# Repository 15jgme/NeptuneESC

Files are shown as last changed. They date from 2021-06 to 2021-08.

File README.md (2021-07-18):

# NeptuneESC
The goal of this project is to create the smallest possible electronic speed controller module for a single motor. This work is essentially Blue Robotic's BlueESC with a different, smaller, board layout. 

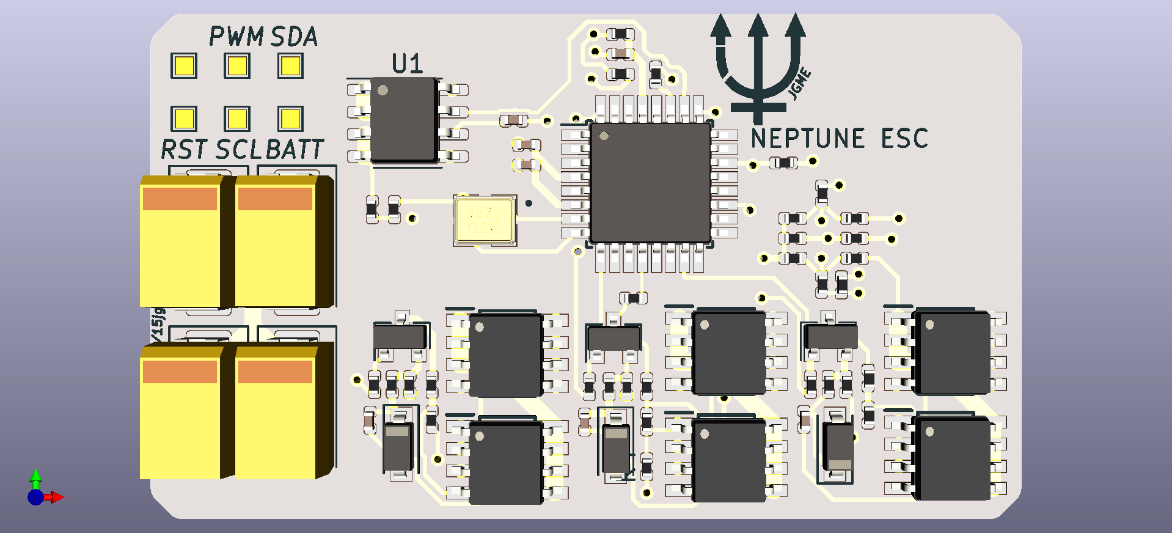
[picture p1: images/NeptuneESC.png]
Board layout


## Quick notes
* Design in KiCad
* ATmega8A-AU MCU
* I2C operations
* 5cm x 3cm size
* Programmable ESC

## Layout

The design is made to be compatable with assembly and board fabrication from [JLCPCB]https://jlcpcb.com/

The current size is about 5cm by 2cm in a single PCB, and is designed to support motors used in midsized UAV applications.

## Usage

As with the BlueESC, Neptune operates on [tgy](https://github.com/bluerobotics/tgy) firmware and can be run off of an I2C connection, making it ideal for daisychaining and tinkering. Note that since this project was in active development tgy is no longer maintained, but the atmega8a-au should allow for a variety of different firmware if desired. 

## State

This project was never assembled, however it is nearly complete. Anyone who needs something similar should have no trouble completing it!
Here's whats left before completion.

* Layout J8 and J7
* Finish about 10 traces and add ground and power planes as desired
* Make better A/B/C channel pads and connectors.
* Electrical checks
* _Fab it!_

If I need a custom ESC I'll continue work on this but until then it's for anyone who can make use of it. Cheers 🍻

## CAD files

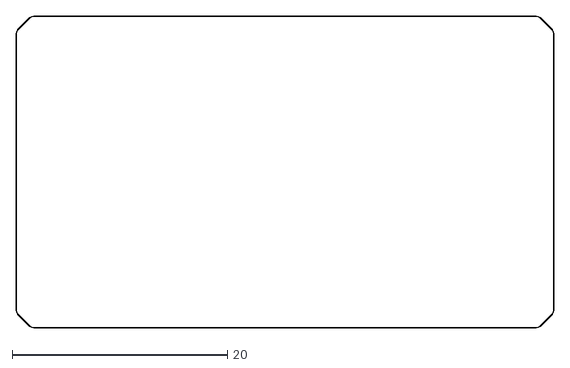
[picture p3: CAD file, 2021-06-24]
Outline/Outline.dxf
50.0 x 29.0

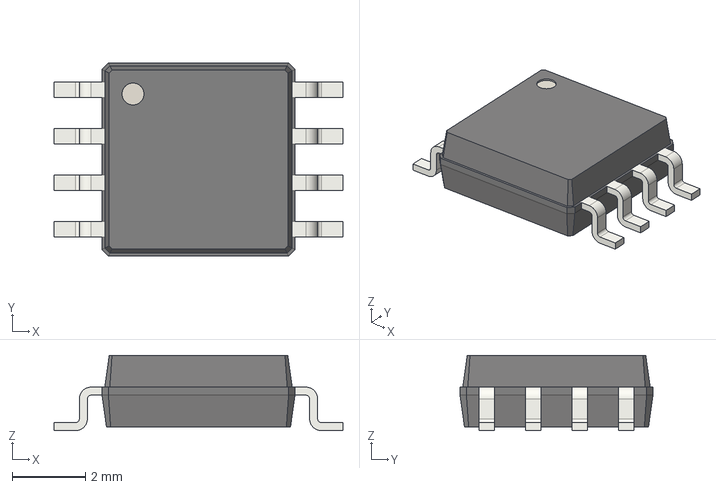
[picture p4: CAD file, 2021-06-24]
Used libraries/SOIC-8_5.275x5.275mm_P1.27mm.step
7.90 x 5.28 x 2.06 mm

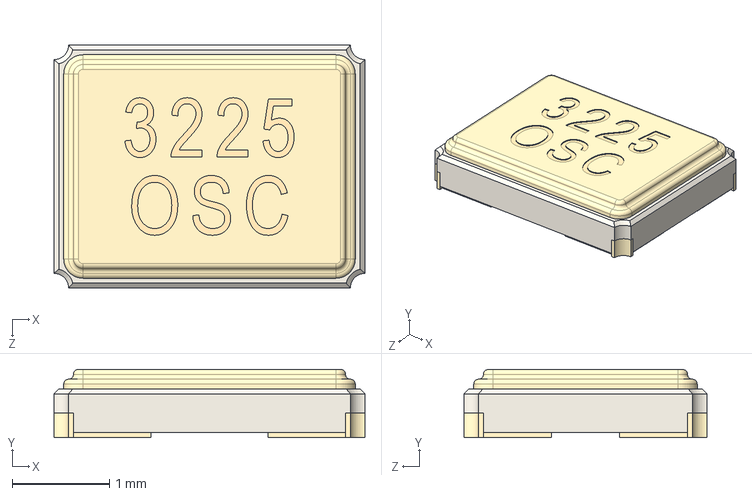
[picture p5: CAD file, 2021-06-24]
Used libraries/3225 SMD Crystal Oscillator.STEP
3.20 x 0.7 x 2.50 mm

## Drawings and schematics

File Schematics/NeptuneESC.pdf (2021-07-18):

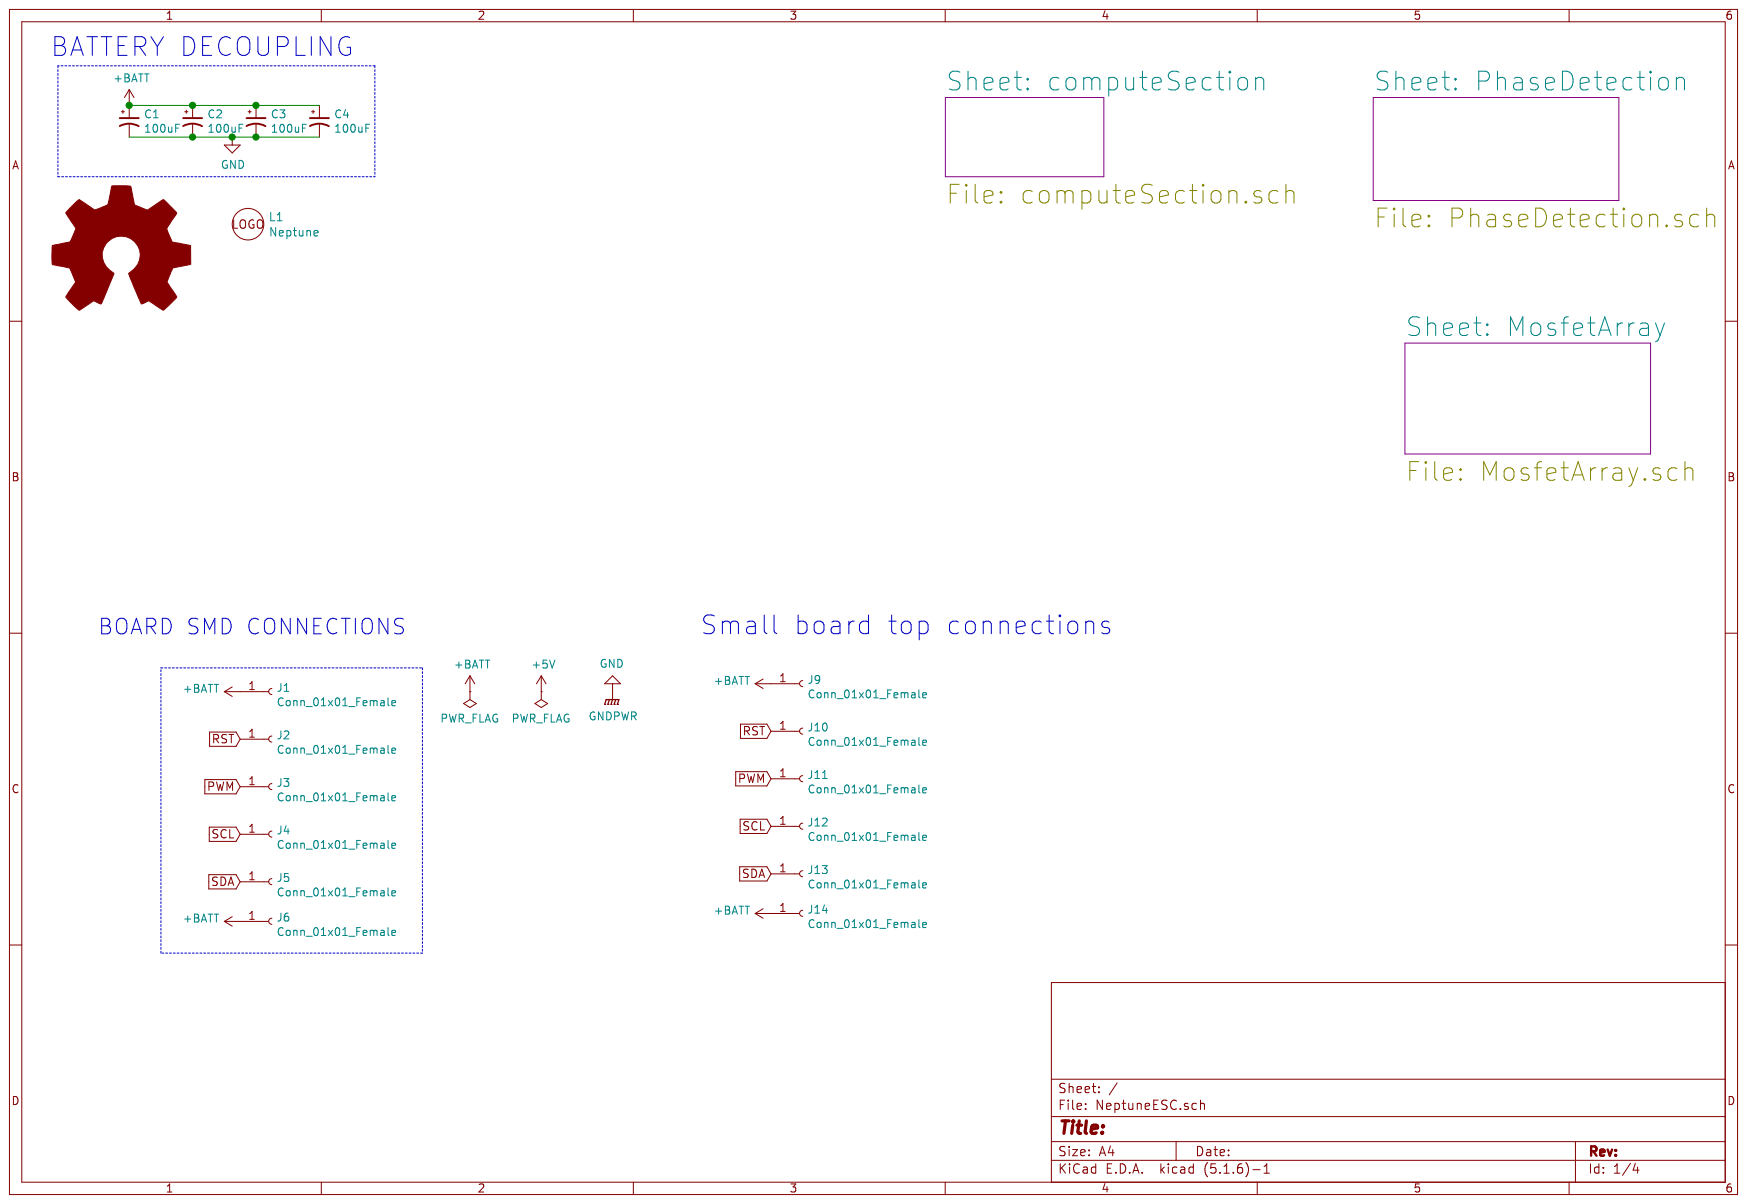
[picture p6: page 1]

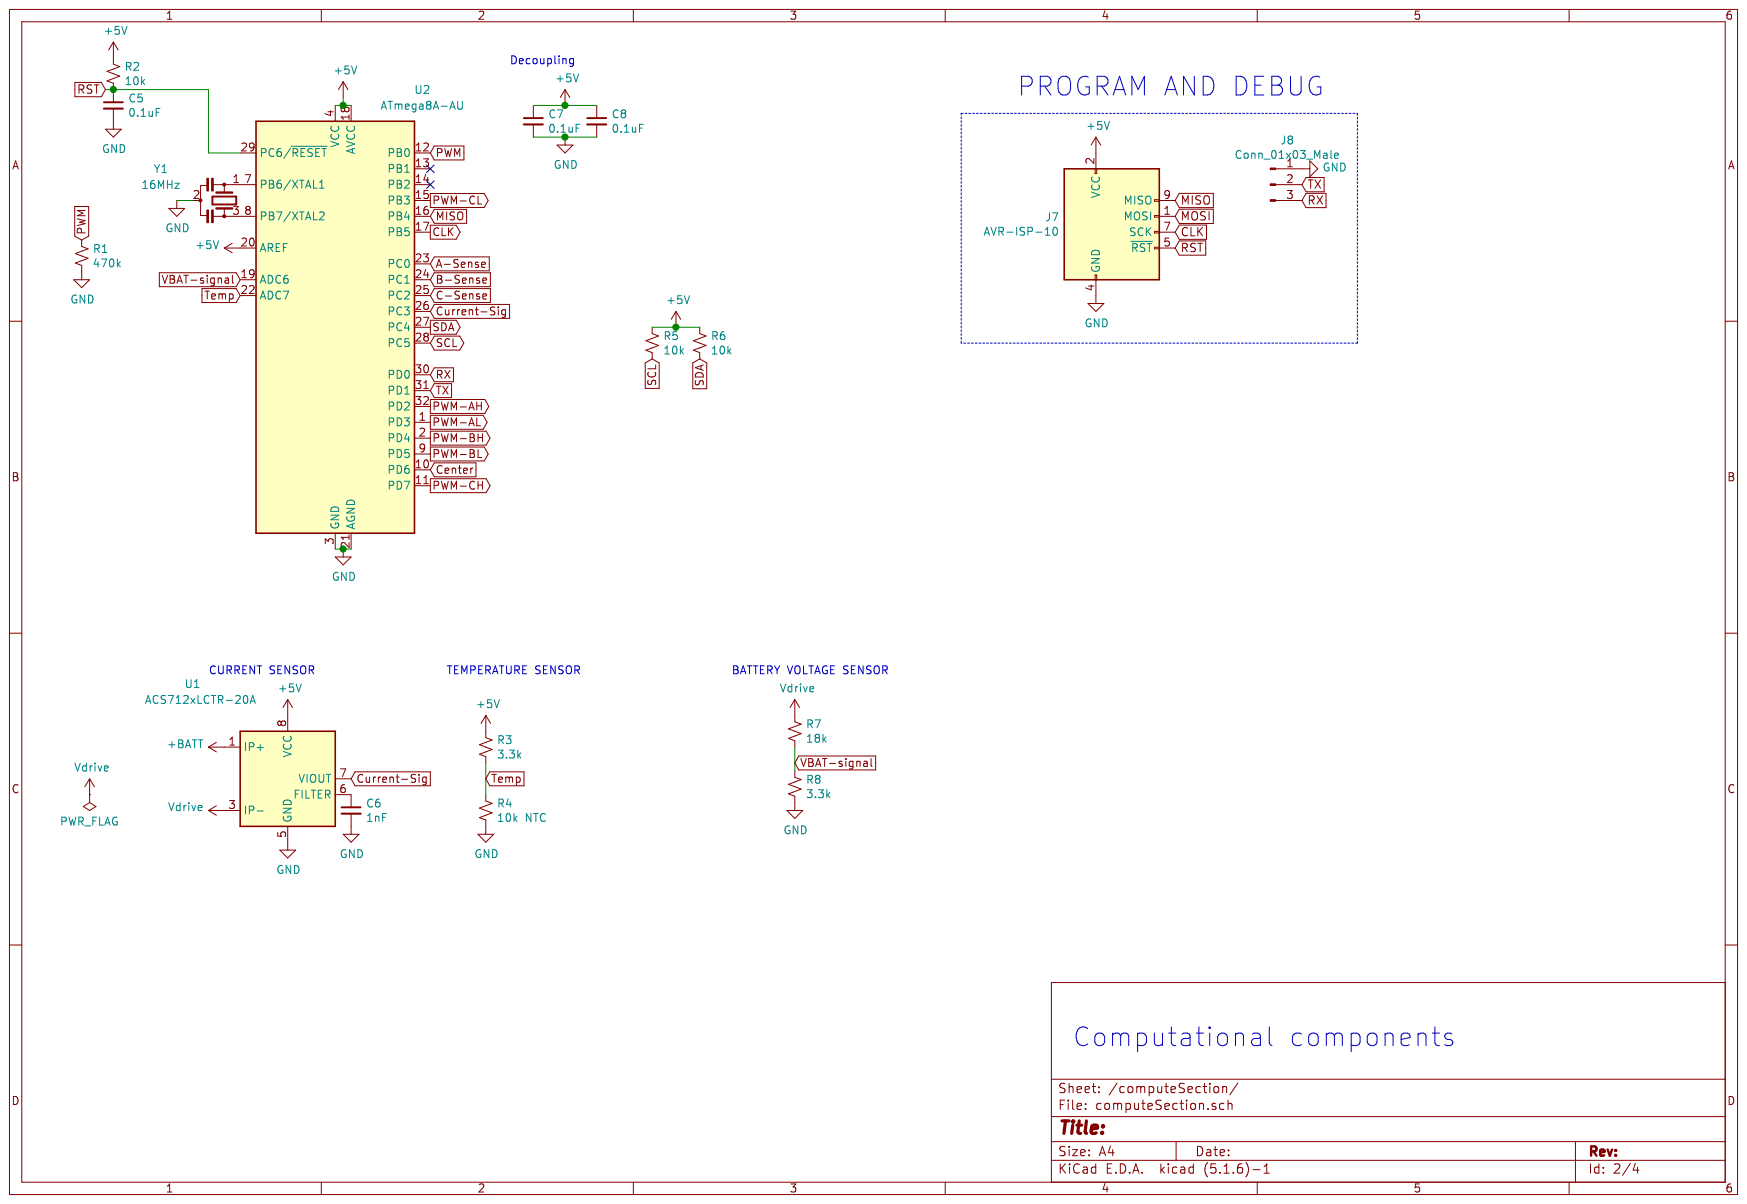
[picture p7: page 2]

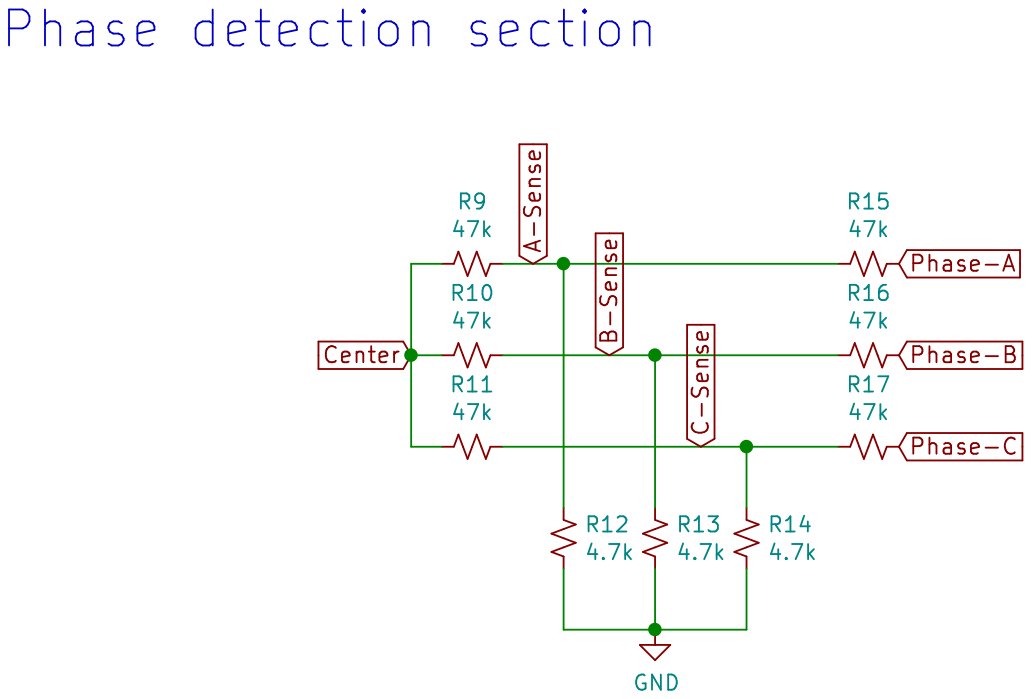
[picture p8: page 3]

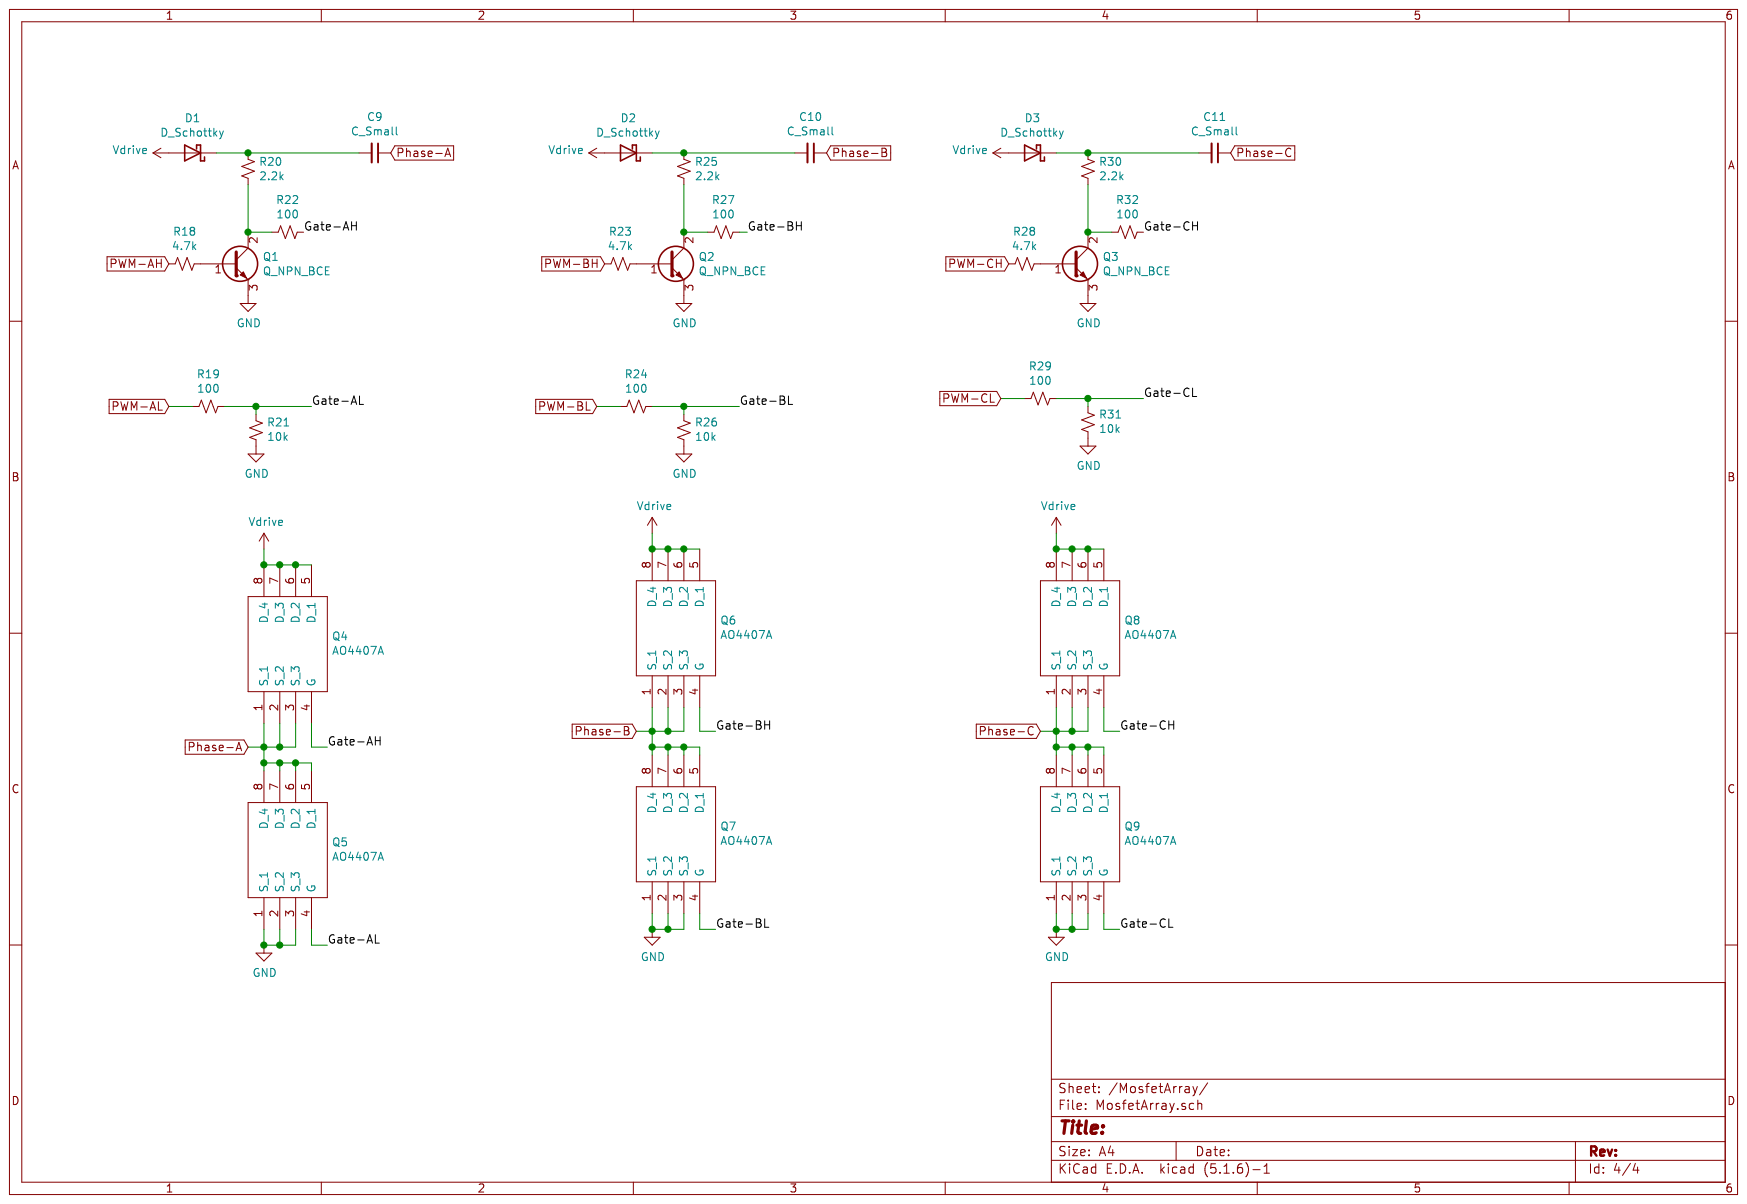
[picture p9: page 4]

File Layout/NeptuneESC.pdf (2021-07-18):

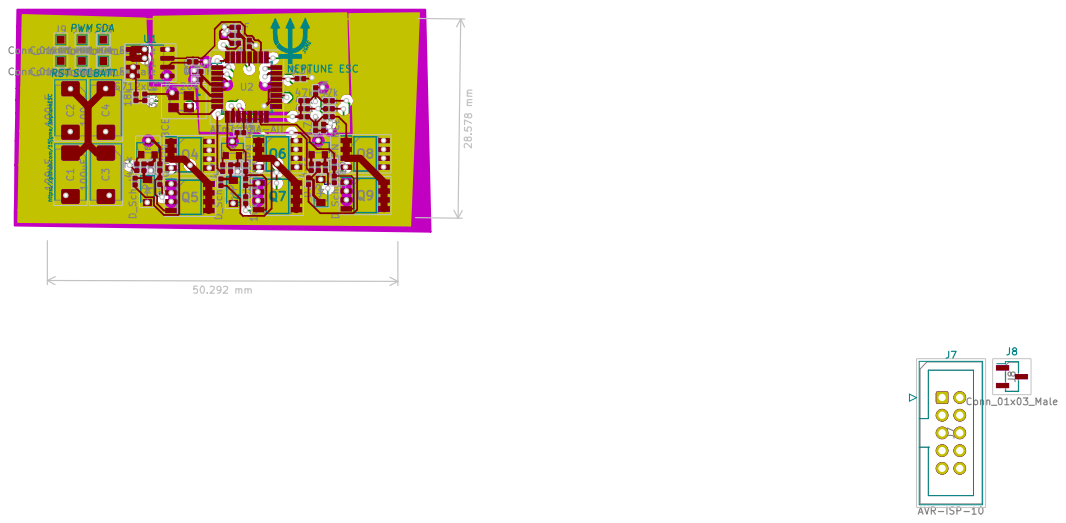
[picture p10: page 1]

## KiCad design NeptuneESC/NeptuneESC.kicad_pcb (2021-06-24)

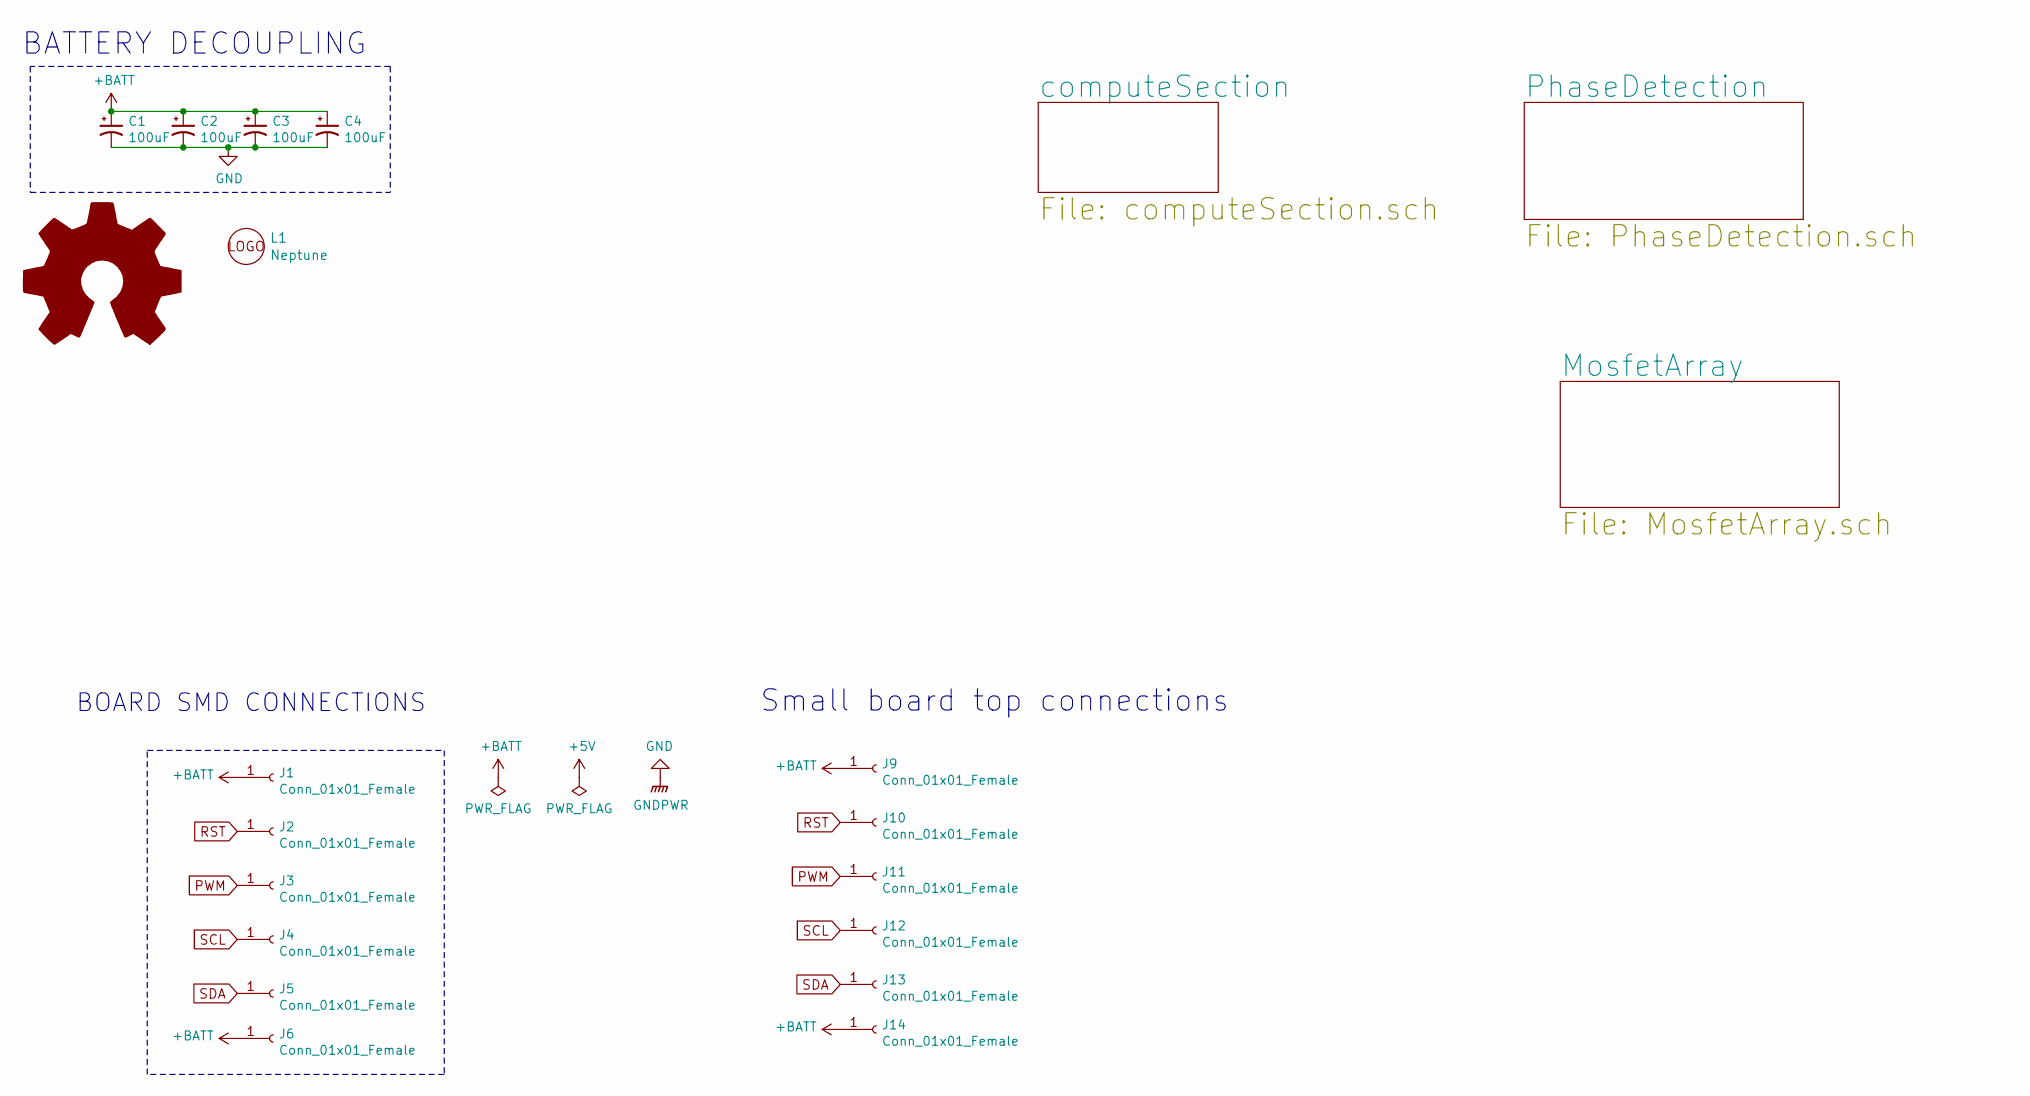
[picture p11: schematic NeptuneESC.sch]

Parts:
C1, C2, C3, C4: 100uF; CP_EIA-7343-43_Kemet-X; JLCPCB C139578
J1, J2, J3, J4, J5, J6: Conn_01x01_Female; TestPoint_Pad_4.0x4.0mm
J9, J10, J11, J12, J13, J14: Conn_01x01_Female; TestPoint_Pad_1.0x1.0mm
L1: Neptune; neptuneLogo

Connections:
+BATT: C1.1, C2.1, C3.1, C4.1, J1.1, J6.1, J9.1, J14.1; also elsewhere on the board
GND: C1.2, C2.2, C3.2, C4.2; also elsewhere on the board
PWM: J3.1, J11.1; also elsewhere on the board
RST: J2.1, J10.1; also elsewhere on the board
SCL: J4.1, J12.1; also elsewhere on the board
SDA: J5.1, J13.1; also elsewhere on the board

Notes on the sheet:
BATTERY DECOUPLING
BOARD SMD CONNECTIONS
Small board top connections

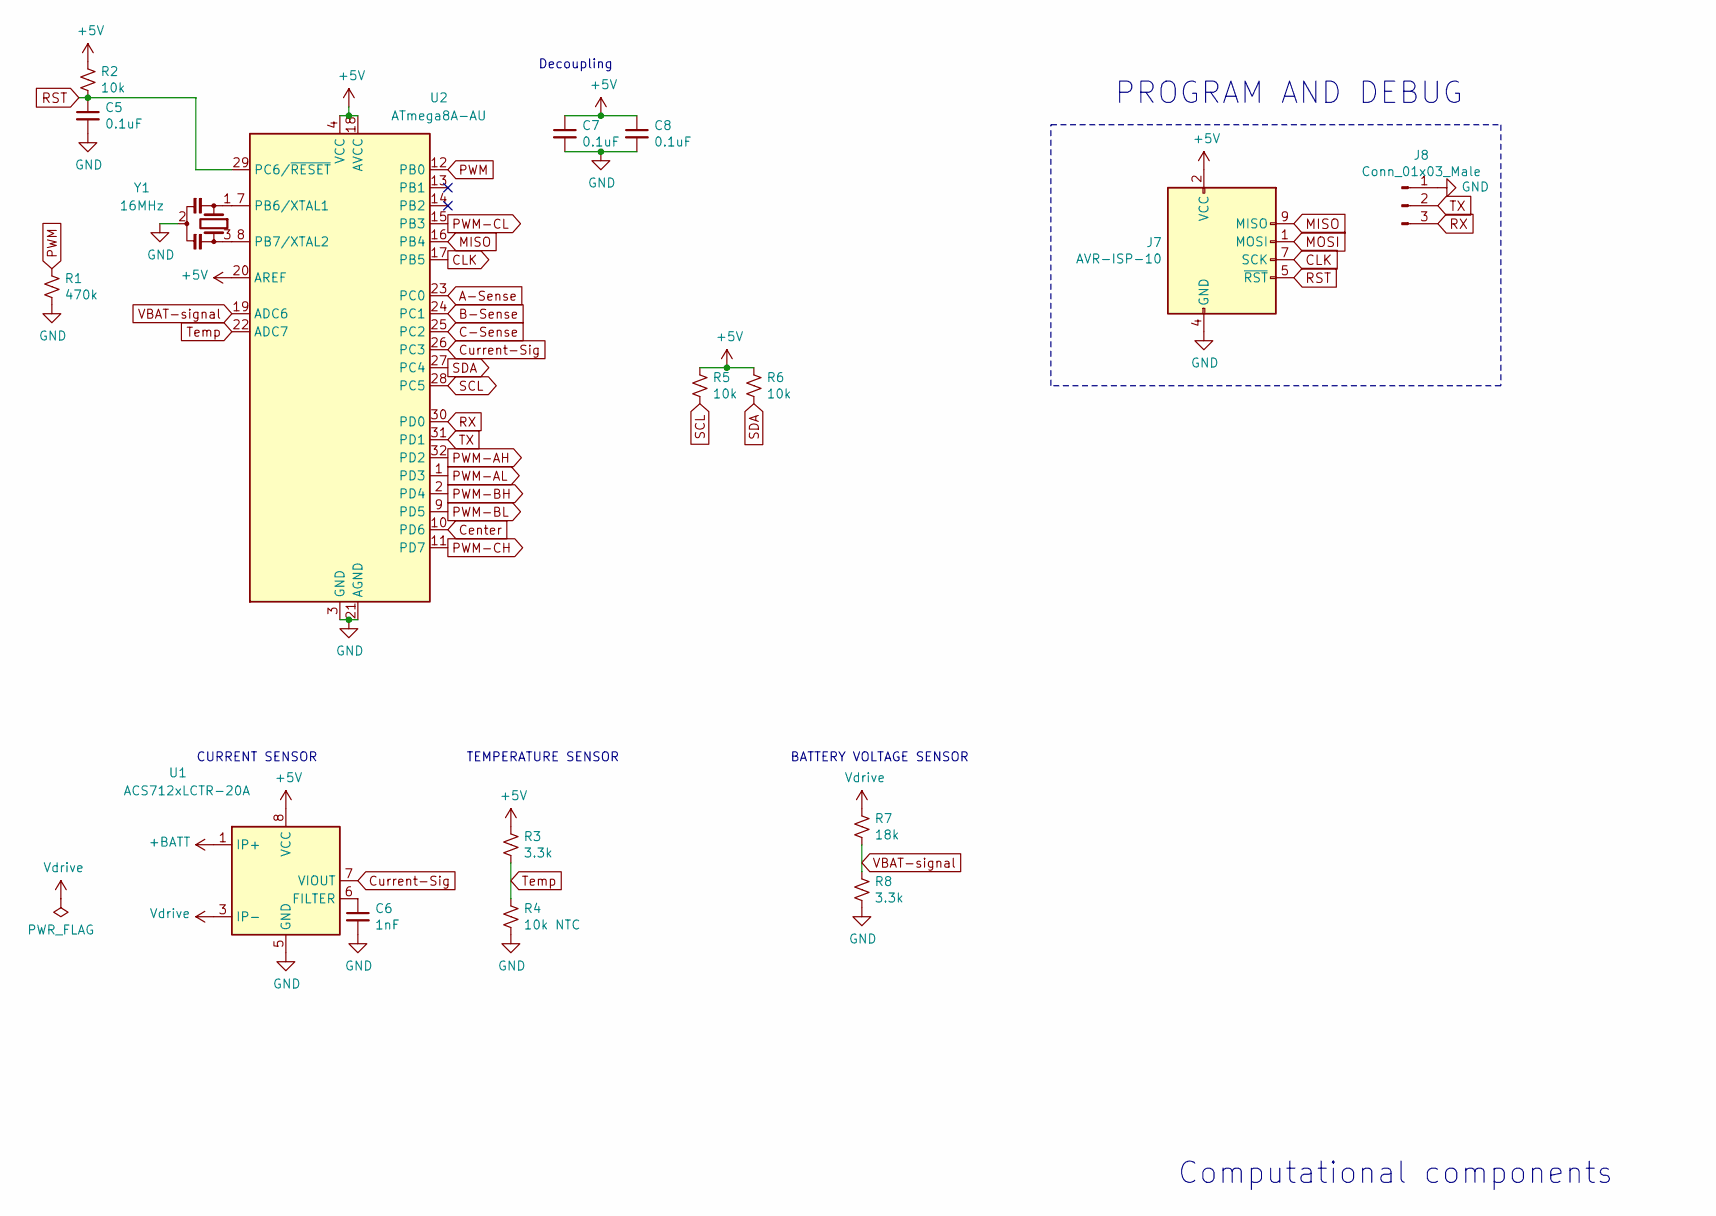
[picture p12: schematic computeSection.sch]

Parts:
C5, C7, C8: 0.1uF; C_0402_1005Metric; JLCPCB C1525
C6: 1nF; C_0402_1005Metric; JLCPCB C1523
J7: AVR-ISP-10; IDC-Header_2x05_P2.54mm_Vertical
J8: Conn_01x03_Male; PinSocket_1x03_P1.27mm_Vertical_SMD_Pin1Left
R1: 470k; R_0402_1005Metric; JLCPCB C25790
R2, R5, R6: 10k; R_0402_1005Metric; JLCPCB C25744
R3, R8: 3.3k; R_0402_1005Metric; JLCPCB C25890
R4: 10k NTC; R_0402_1005Metric; JLCSMT C92371
R7: 18k; R_0402_1005Metric; JLCPCB C25762
U1: ACS712xLCTR-20A; SOIC-8_3.9x4.9mm_P1.27mm
U2: ATmega8A-AU; TQFP-32_7x7mm_P0.8mm; JLCPCB C16190
Y1: 16MHz; X322516MLB4SI; JLCPCB C13738

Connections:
+5V: C7.1, C8.1, J7.2 (VCC), R2.1, R3.1, R5.1, R6.1, U1.8 (VCC), U2.4 (VCC), U2.6 (VCC), U2.18 (AVCC), U2.20 (AREF)
+BATT: U1.1 (IP+), U1.2 (IP+); also elsewhere on the board
A-Sense: U2.23 (PC0); also elsewhere on the board
B-Sense: U2.24 (PC1); also elsewhere on the board
C-Sense: U2.25 (PC2); also elsewhere on the board
CLK: J7.7 (SCK), U2.17 (PB5)
Center: U2.10 (PD6); also elsewhere on the board
Current-Sig: U1.7 (VIOUT), U2.26 (PC3)
GND: C5.2, C6.2, C7.2, C8.2, J7.4 (GND), J7.6 (GND), J7.8 (GND), J7.10 (GND), J8.1, R1.2, R4.2, R8.2, U1.5 (GND), U2.3 (GND), U2.5 (GND), U2.21 (AGND), Y1.2; also elsewhere on the board
MISO: J7.9 (MISO), U2.16 (PB4)
MOSI: J7.1 (MOSI)
unnamed: C6.1, U1.6 (FILTER)
unnamed: U2.7 (PB6/XTAL1), Y1.1
unnamed: U2.8 (PB7/XTAL2), Y1.3
PWM: R1.1, U2.12 (PB0); also elsewhere on the board
PWM-AH: U2.32 (PD2); also elsewhere on the board
PWM-AL: U2.1 (PD3); also elsewhere on the board
PWM-BH: U2.2 (PD4); also elsewhere on the board
PWM-BL: U2.9 (PD5); also elsewhere on the board
PWM-CH: U2.11 (PD7); also elsewhere on the board
PWM-CL: U2.15 (PB3); also elsewhere on the board
RST: C5.1, J7.5 (~RST), R2.2, U2.29 (PC6/~RESET); also elsewhere on the board
RX: J8.3, U2.30 (PD0)
SCL: R5.2, U2.28 (PC5); also elsewhere on the board
SDA: R6.2, U2.27 (PC4); also elsewhere on the board
TX: J8.2, U2.31 (PD1)
Temp: R3.2, R4.1, U2.22 (ADC7)
VBAT-signal: R7.2, R8.1, U2.19 (ADC6)
Vdrive: R7.1, U1.3 (IP-), U1.4 (IP-); also elsewhere on the board

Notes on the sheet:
Decoupling
CURRENT SENSOR
TEMPERATURE SENSOR
BATTERY VOLTAGE SENSOR
Computational components
PROGRAM AND DEBUG

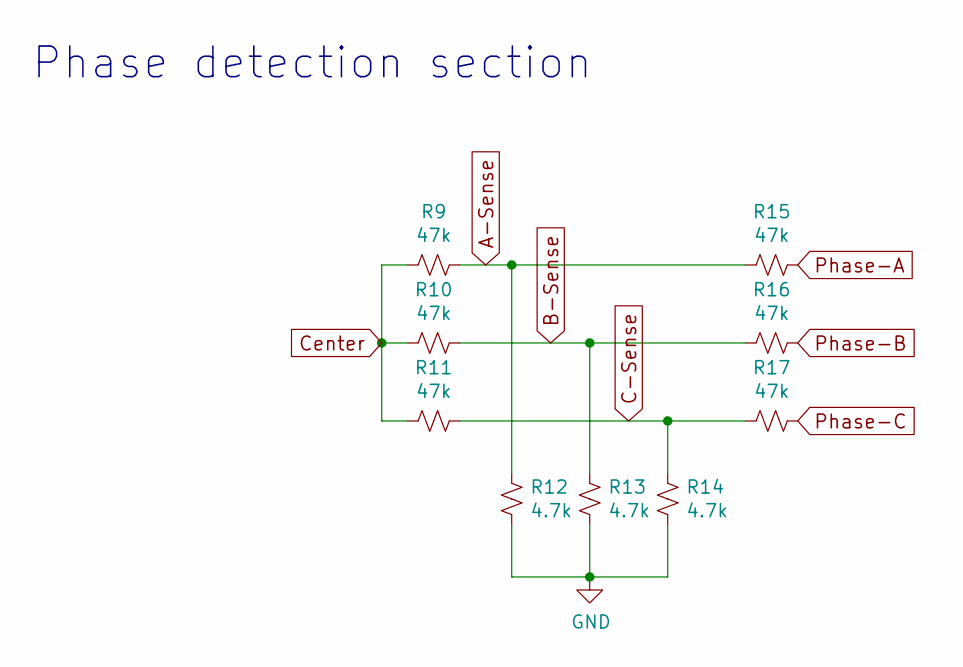
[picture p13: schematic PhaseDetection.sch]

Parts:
R9, R10, R11, R15, R16, R17: 47k; R_0402_1005Metric; JLCPCB C25792
R12, R13, R14: 4.7k; R_0402_1005Metric; JLCPCB C25900

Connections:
A-Sense: R9.1, R12.1, R15.2; also elsewhere on the board
B-Sense: R10.1, R13.1, R16.2; also elsewhere on the board
C-Sense: R11.1, R14.1, R17.2; also elsewhere on the board
Center: R9.2, R10.2, R11.2; also elsewhere on the board
GND: R12.2, R13.2, R14.2; also elsewhere on the board
Phase-A: R15.1; also elsewhere on the board
Phase-B: R16.1; also elsewhere on the board
Phase-C: R17.1; also elsewhere on the board

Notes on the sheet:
Phase detection section

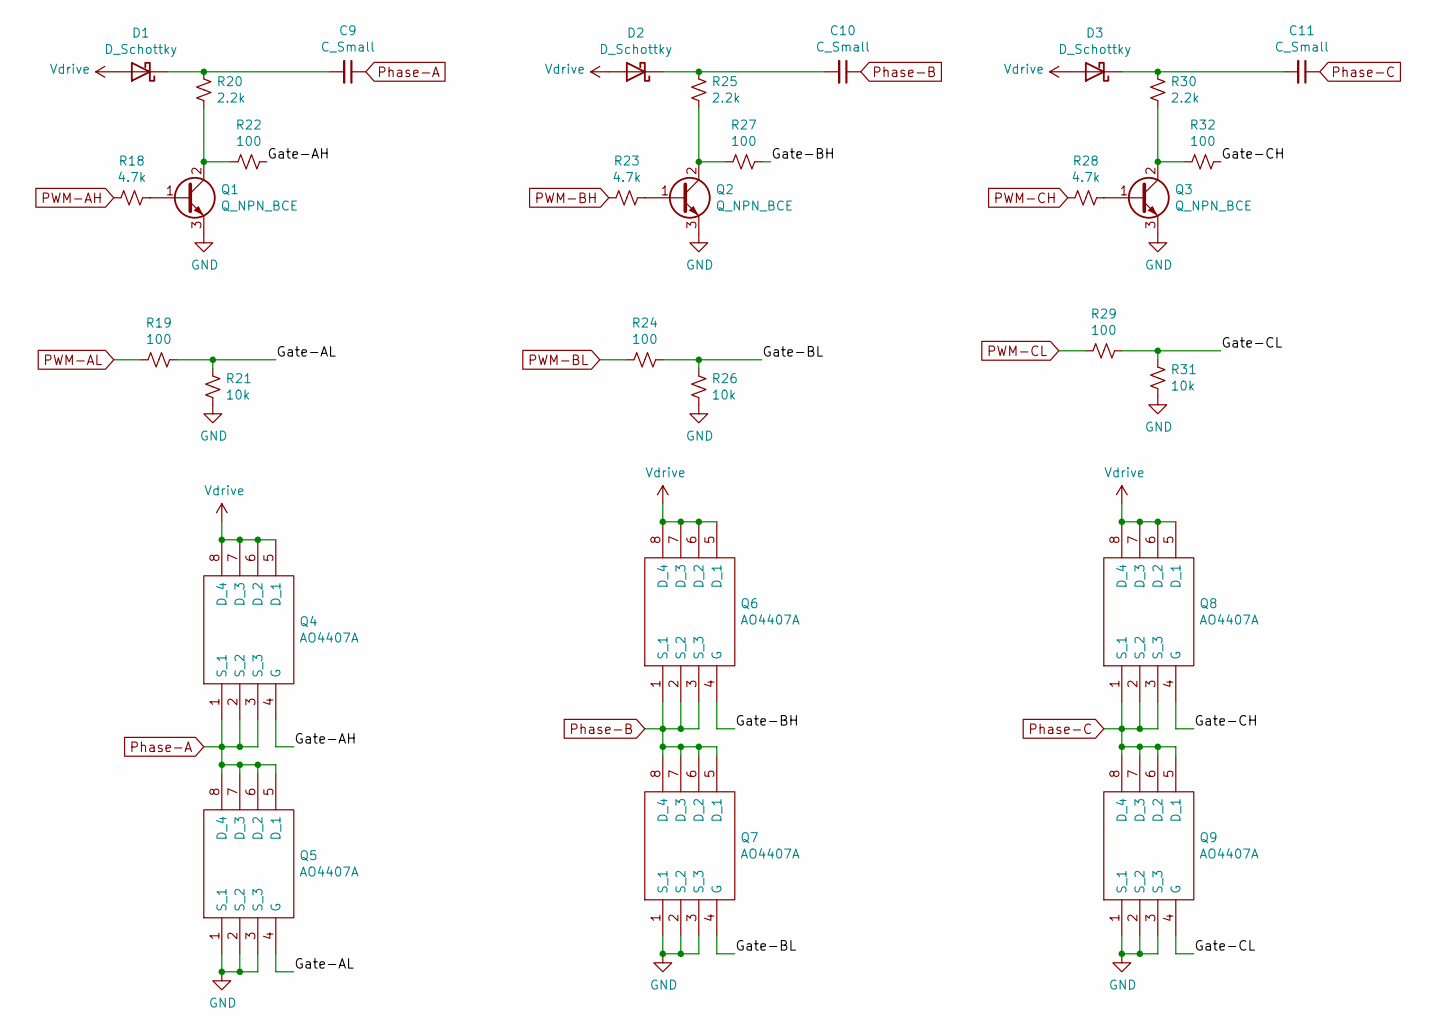
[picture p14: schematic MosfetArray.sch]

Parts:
C9, C10, C11: C_Small; C_0402_1005Metric
D1, D2, D3: D_Schottky; D_SOD-123; JLCPCB C8598
Q1, Q2, Q3: Q_NPN_BCE; SOT-23; JLCPCB C2150
Q4, Q5, Q6, Q7, Q8, Q9: AO4407A; SOIC127P600X175-8N; Manufacturer_Part_Number AO4407A; JLCPCB C16072
R18, R23, R28: 4.7k; R_0402_1005Metric; JLCPCB C25900
R19, R22, R24, R27, R29, R32: 100; R_0402_1005Metric; JLCPCB C25741
R20, R25, R30: 2.2k; R_0402_1005Metric; JLCPCB C25879
R21, R26: 10k; R_0402_1005Metric; JLCPCB C25744
R31: 10k; R_0402_1005Metric

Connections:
/MosfetArray/Gate-AH: Q4.4 (G), R22.1
/MosfetArray/Gate-AL: Q5.4 (G), R19.1, R21.2
/MosfetArray/Gate-BH: Q6.4 (G), R27.1
/MosfetArray/Gate-BL: Q7.4 (G), R24.1, R26.2
/MosfetArray/Gate-CH: Q8.4 (G), R32.1
/MosfetArray/Gate-CL: Q9.4 (G), R29.1, R31.2
GND: Q1.3 (E), Q2.3 (E), Q3.3 (E), Q5.1 (S_1), Q5.2 (S_2), Q5.3 (S_3), Q7.1 (S_1), Q7.2 (S_2), Q7.3 (S_3), Q9.1 (S_1), Q9.2 (S_2), Q9.3 (S_3), R21.1, R26.1, R31.1; also elsewhere on the board
unnamed: C9.2, D1.1 (K), R20.1
unnamed: C10.2, D2.1 (K), R25.1
unnamed: C11.2, D3.1 (K), R30.1
unnamed: Q1.1 (B), R18.1
unnamed: Q1.2 (C), R20.2, R22.2
unnamed: Q2.1 (B), R23.1
unnamed: Q2.2 (C), R25.2, R27.2
unnamed: Q3.1 (B), R28.1
unnamed: Q3.2 (C), R30.2, R32.2
PWM-AH: R18.2; also elsewhere on the board
PWM-AL: R19.2; also elsewhere on the board
PWM-BH: R23.2; also elsewhere on the board
PWM-BL: R24.2; also elsewhere on the board
PWM-CH: R28.2; also elsewhere on the board
PWM-CL: R29.2; also elsewhere on the board
Phase-A: C9.1, Q4.1 (S_1), Q4.2 (S_2), Q4.3 (S_3), Q5.5 (D_1), Q5.6 (D_2), Q5.7 (D_3), Q5.8 (D_4); also elsewhere on the board
Phase-B: C10.1, Q6.1 (S_1), Q6.2 (S_2), Q6.3 (S_3), Q7.5 (D_1), Q7.6 (D_2), Q7.7 (D_3), Q7.8 (D_4); also elsewhere on the board
Phase-C: C11.1, Q8.1 (S_1), Q8.2 (S_2), Q8.3 (S_3), Q9.5 (D_1), Q9.6 (D_2), Q9.7 (D_3), Q9.8 (D_4); also elsewhere on the board
Vdrive: D1.2 (A), D2.2 (A), D3.2 (A), Q4.5 (D_1), Q4.6 (D_2), Q4.7 (D_3), Q4.8 (D_4), Q6.5 (D_1), Q6.6 (D_2), Q6.7 (D_3), Q6.8 (D_4), Q8.5 (D_1), Q8.6 (D_2), Q8.7 (D_3), Q8.8 (D_4); also elsewhere on the board

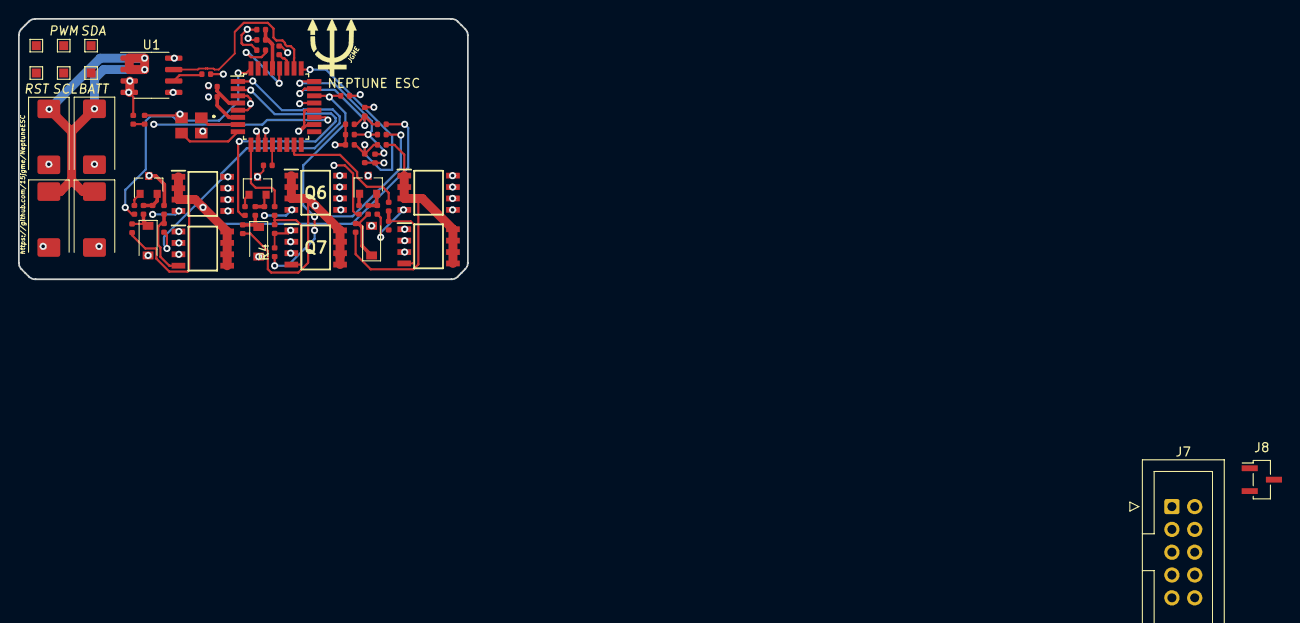
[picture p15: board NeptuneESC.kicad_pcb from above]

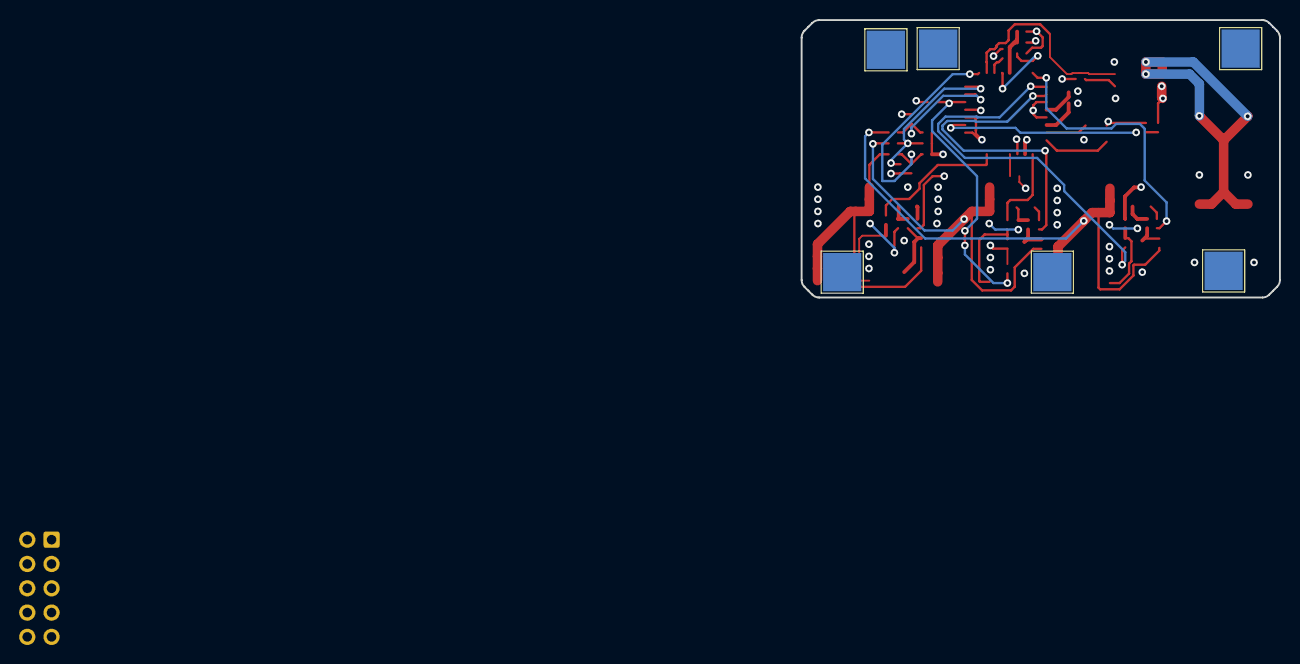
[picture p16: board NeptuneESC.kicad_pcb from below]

Board: 4 copper layers, 50.0 x 29.0 mm, 73 parts (6 on the bottom side), 46 nets.

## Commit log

2020-05-24 Kicad issues >:(
    [MosfetArray.sch, NeptuneESC.kicad_pcb, NeptuneESC.sch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]
2020-05-27 Innitial layout
    Need to add motor pads
    [3225 SMD Crystal Oscillator.STEP, MosfetArray.sch, NeptuneESC.sch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]

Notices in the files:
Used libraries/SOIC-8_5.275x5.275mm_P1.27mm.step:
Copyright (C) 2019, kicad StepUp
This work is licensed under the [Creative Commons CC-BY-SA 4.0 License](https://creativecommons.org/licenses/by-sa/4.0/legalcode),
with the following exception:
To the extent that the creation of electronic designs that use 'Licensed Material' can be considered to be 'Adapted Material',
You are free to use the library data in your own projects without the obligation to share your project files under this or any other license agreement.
